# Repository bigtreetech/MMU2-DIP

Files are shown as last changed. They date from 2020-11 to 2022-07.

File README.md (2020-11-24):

# MMU2-DIP
Ported from [pruas3D](https://github.com/prusa3d/MM-control-01)  
Mcu: stm32f0c8  
Supports all types of drivers for bigtreetech,  
Supports TMC stall protection (tmc2209,tmc2130),  
Supports manual loading of filaments,  

# Modify configuration  
In firmware/MMU2/src/config.h  
Set the drive type, motor current, etc.

# Building  
It is recommended to use vscode to install the PlatformIO plugin for compilation.  

# Upgrade firmware in Windows  
1. Install firmware/Tool/cd340driver/CH341SER.EXE.  
2. Connect the usb  
3. Open firmware/Tool/flymcu/FlyMcu.exe.  
  ①. refreshing the port.  
  ②. select the corresponding port.  
  ③. setting the baud rate.  
  ④. Select the firmware.hex file.  
  ⑤. Set download parameters.  
  ⑥. click to start downloading.  
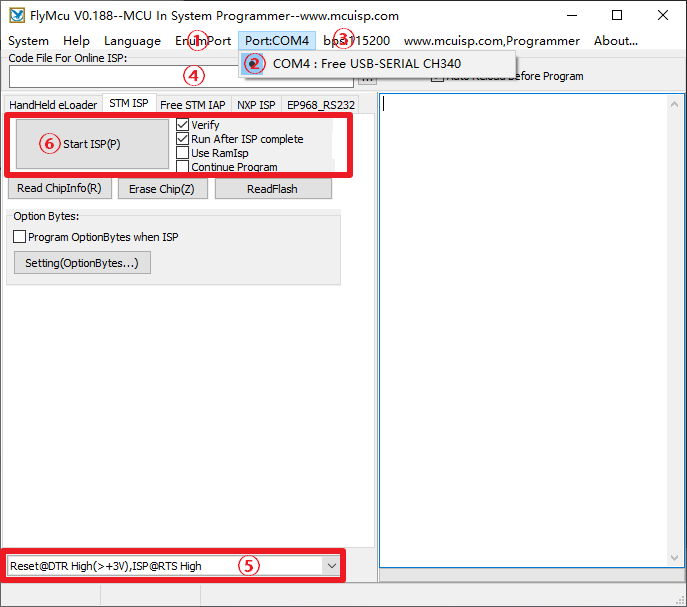
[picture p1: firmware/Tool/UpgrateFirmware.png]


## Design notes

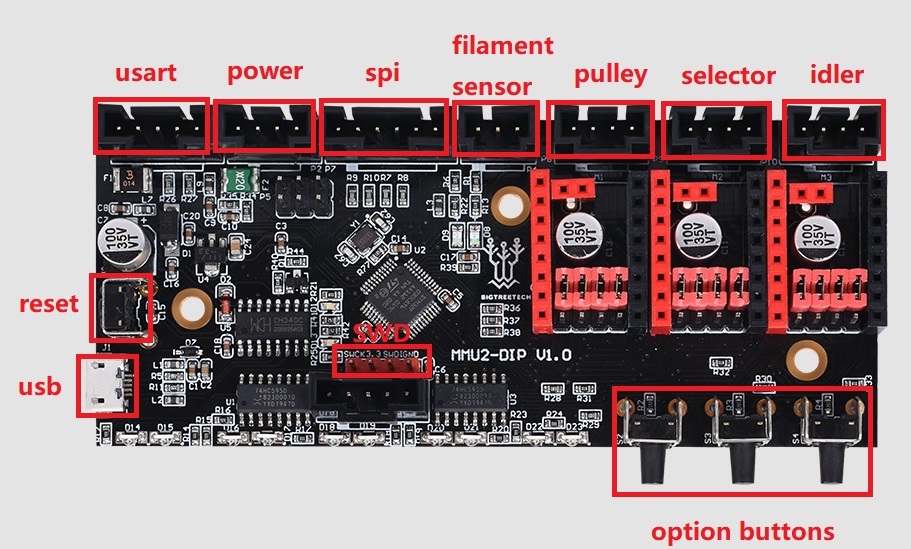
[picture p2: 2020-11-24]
firmware/Tool/ＭＭＵ2-DIP.jpg

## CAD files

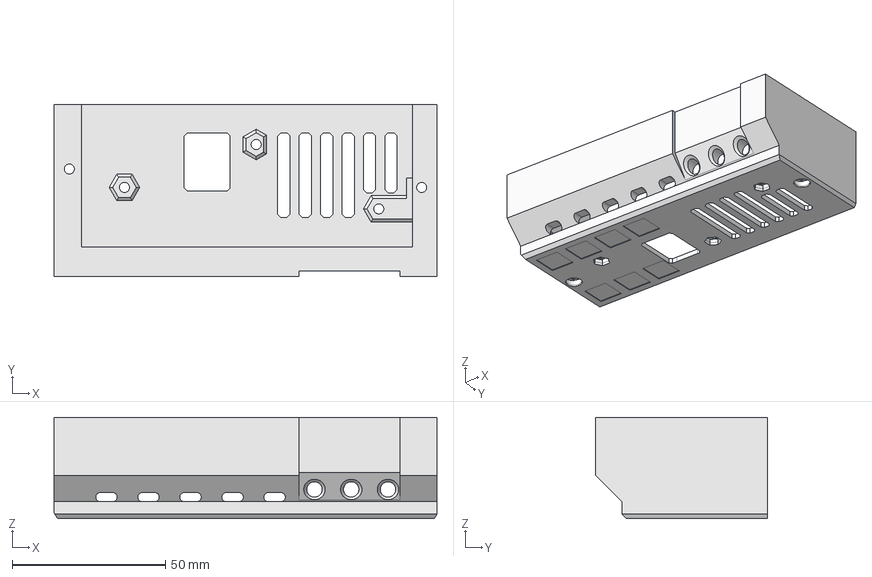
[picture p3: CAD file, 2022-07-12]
3DModel/STEP/mmu2-dip-ele-cover-v2.step
125.0 x 56.0 x 33.0 mm
prism016
prism017
text
Line001
Line
Line002
Line006
Line003
Line004
Line005
Line007
Line010
Line008
Line009
Line011
Line012
Line013
Line014
Line016
Line018
Line021
Line015
Line017
Line019
Line020
Line022
Line025
Line023
Line024
Line026
Line027
Line028
Line029
Line036
Line030
Line031
Line032
Line033
Line034
Line035
Line037
Line040
Line038
Line039
Line041
prism001
prism
prism002
prism003
prism004
frustum
frustum001
prism006
frustum002
prism007
RefineLinearExtrude
LinearExtrude
prism005
prism012
prism013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

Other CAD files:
3DModel/mmu2-dip-ele-cover-v2.stl

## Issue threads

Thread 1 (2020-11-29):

can't compile

gabwhoop, 2020-11-29:
any manual to how to compile mmu2 firmware???? this manual is not complete, im using vscode to compile my printers firmware without any issues but with mmu2 the check mark to compile doen't apear....big thanx im sorry for my english

bigtreetech, 2020-12-01:
Hi, we have tested the firmware to compile. You may need to wait for vscode to download the library.

gabwhoop, 2020-12-01:
ok big thanx my problem was i try to open the file using vscode instead platformIO thanx for your time

Closed 2020-12-02.

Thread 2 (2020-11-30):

pinout  and diagram

kakou-fr, 2020-11-30:
Hi,

Could you provide the pinout and shematics of this board in order to port the klipper firmware  on it.

bigtreetech, 2020-12-01:
OK, we have joined the plan

kakou-fr, 2020-12-01:
hi, i dont see any schematic in the current maaster

kakou-fr, 2020-12-09:
?

tobyworks, 2020-12-24:
Please provide a good pinout for this board like the skr 1.3 pinout diagram. We need to know the pin numbers for the steppers

tobyworks, 2021-01-02:
?

pstit006, 2021-01-05:
Has anyone got this board to work?

ellensp, 2022-03-31:
Circuit diagram have just been uploaded https://github.com/bigtreetech/MMU2-DIP/blob/master/hardware/MMU2-DIP.PDF

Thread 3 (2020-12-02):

MMU2-DIP no connect on mk3s

austaquio32, 2020-12-02:
Good afternoon, I'm trying to get your board to connect with a mk3s and it's impossible, I let the mk3s fully charge and restart the mmu2s-dip board and it still doesn't connect, do you have to change any position wire? Thank you very much.

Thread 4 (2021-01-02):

Can not connect skr 1.4 turbo

pstit006, 2021-01-02:
I have tried and tried I cannot get the mmu2 dip to communicate with the skr 1.4 turbo

pstit006, 2021-01-05:
Can anybody help

XylenC4, 2021-01-06:
I've got it working.
[Configuration_adv.txt](https://github.com/bigtreetech/MMU2-DIP/files/5777667/Configuration_adv.txt)
[Configuration.txt](https://github.com/bigtreetech/MMU2-DIP/files/5777668/Configuration.txt)

I'm using the TFT Socket so SERIAL0. To use this port it has to be disabled for general G-Command usage
//#define SERIAL_PORT_2 0

last but not least you have to define the Port (Serial is SERIAL0)
 // #define MMU2_SERIAL_PORT 0
  #define MMU2_SERIAL Serial

Make sure you're serial connection is connected right!
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

pstit006, 2021-01-06:
Ok I will give that a try I'm running a tft70 and I watched a video for using the i2c serial as serial 3 so I could keep my tft

XylenC4, 2021-01-06:
If you only use MARLIN Mode on the TFT (as I do) it will work without Serial0

pstit006, 2021-01-16:
Ok I've been trying to get this board to work I'm using the btt mmu2-dip board with tmc2209 drivers I've tried connecting to the tft port and still not talking to the mmu2-dip

AJAX2500, 2021-02-06:
Hey guys. I spent a lot of time smashing my head against a wall on trying to get the MMU board to connect to any board running 2.0.7.2 and ultimately I found that in the version.h of the MMU firmware file there is the following line.

static const uint16_t fw_buildnr = 130; //!< number of commits preceeding current HEAD

Once I changed this to the following everything connected up and worked perfect.

static const uint16_t fw_buildnr = 132; //!< number of commits preceeding current HEAD

Hope this is helpful to you!

Ven827, 2023-09-12:
Hey, just having a similar issue, my serial port seems to be 3.3V while the MMU2 needs 5V, I plugged it into a different 5V source and it works but I wasn't able to get any communication to happen. I'm also not able to compile if I comment out #define MMU2_SERIAL_PORT 0. Any help would be appreciated.

XylenC4, 2023-09-12:
I'll haven't compiled Marlin for a while as I'll moved over to a SKR PICO and KLIPPER and a Palette 2+ so take my answer with a grain of salt...

You shouldn't comment it out but replace the #define MMU2_SERIAL_PORT 0 with #define MMU2_SERIAL Serial. The MMU will require a serial port for communication, so there is no sense on disabling the port by removing the line.

Use a USB -> Serial Port adapter to verify the TTL (5V) serial communication to the MMU and the communication to your main board (which one do you use).

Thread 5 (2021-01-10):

Calibrate bowden length not working?

eightheads, 2021-01-10:
I cannot seem to calibrate the bowden length in the service menu of the MMU2. I can get to the menu, and to the calibrate section(selection #4), but when trying to start the calibration process it just blinks a single red LED on the #1 filament spot.

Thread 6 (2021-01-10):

MMU2 doesn't connect with GTR 1.0

av71966, 2021-01-10:
Hi. I tried to connect MMU2 to GTR 1.0 Board.  I connect it to UART3 (TFT connection)
MMU can reset from LCD menu, but don't load\uload filament and don't homing.
Marlin 2.0.7.4

Configuration
#define SERIAL_PORT -1
#define SERIAL_PORT_2 3

Configuration_adv
  #define MMU2_SERIAL_PORT 3
  #define MMU2_SERIAL Serial3

What's wrong?

XylenC4, 2021-01-14:
check out this thread (even if you use another board / chipset)

https://github.com/bigtreetech/MMU2-DIP/issues/4

-> Disable #define SERIAL_PORT_2 3 and #define MMU2_SERIAL_PORT 3

av71966, 2021-01-14:
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

Hi, i use UART 3 for TFT now. I tried to use serial Port 2 (ruspberry port) and have the same result...
If i want to use serial port 2 i need only define MMU2_SERIAL_PORT 2 and comment MMU2_SERIAL in Configuration ADV?

XylenC4, 2021-01-14:
You will need a separate serial connection to get this working.

//#define SERIAL_PORT_2 3
//#define MMU2_SERIAL_PORT 3
#define MMU2_SERIAL Serial2

I'm using the TFT but only in MARLIN MODE so no Serial Connection is needed for my TFT!

I recommend plugging in a Serial to USB connection to check if the connection is working. On Reset you will see an X0 sended by MARLIN.

av71966, 2021-01-21:
I fix problem.
Update marlin to new bugfix. Now it work perfect on uart6
https://github.com/MarlinFirmware/Marlin/pull/20771

pstit006, 2021-01-21:
How did you get the mmu2-dip to work can you provide a configuration and can you share a picture of how you have it hooked up I still can't seem to get this board working

Montezuma-69, 2021-05-18:
Av71966 Same problem here.
#define MMU2_SERIAL Serial3
works with TFT port

but

#define MMU2_SERIAL Serial6
does not work on USART6 at the WIFI port.

What did you set in configuration_adv.h?
Thank you so much

Closed 2021-01-21.

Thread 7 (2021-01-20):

Flash firmware without a Windows PC

iShavgula, 2021-01-20:
Hello,

Is there a way to flash the firmware using an Unix system, maybe via a ST-Link ?
What would the address be ?

Would be nice if there already was some documentation about this part.

Thanks

timurey, 2021-02-12:
Hello,
Use next command to flash firmware with st-link v.2 in `.pio/build/MMU2_F030C8` directory:
`openocd -f interface/stlink-v2.cfg -f target/stm32f0x.cfg -c "init; reset halt; stm32f0x unlock 0; reset halt; flash write_image erase firmware.hex; reset; exit"`

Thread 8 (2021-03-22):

Baudrate

Nickjallday, 2021-03-22:
So I can only get the mmu2-dip to connect to the SKR 1.4 via the i2c ports. Which it works.

I have two questions

1. how can I set the serial interface to 250000 bps instead of 115200. I would like my printer to be on 250000 bps. But when I adjust the uart1 in the config.h I can only get it to communicate with the SKR at 115200 bps.

side note: flymcu only allows communication at 115200 and 256000.

2. At 115200 I can get the mmu2 to communicate and print but it randomly drops communication and reboots the SKR. The terminal is flooded with “prevented cold extrusion” right before it reboots.

side note: I’m running a raspberry pi on the tft serial port.

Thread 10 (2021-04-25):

firmware.hex

nonaak, 2021-04-25:
where can i find firmware.hex?
or do i have to make it my self in platformIO?

Marlin display say "update mmu firmware" or do i somthing wrong? i folow the youtube of Chris Riley

thanks

ellensp, 2022-03-26:
Marlin has function
```CPP
/*
* Check if MMU has compatible firmware
 */
void MMU2::check_version() {
  if (buildnr < MMU_REQUIRED_FW_BUILDNR) {
    SERIAL_ERROR_MSG("Invalid MMU2 firmware. Version >= " STRINGIFY(MMU_REQUIRED_FW_BUILDNR) " required.");
    kill(GET_TEXT_F(MSG_KILL_MMU2_FIRMWARE));
  }
}

so it the firmware value  read form the mmu2 is less than MMU_REQUIRED_FW_BUILDNR
It will tell you to update the firmware

In Marlin MMU_REQUIRED_FW_BUILDNR is set with

`#define MMU_REQUIRED_FW_BUILDNR TERN(MMU2_MODE_12V, 132, 126)
`
Which says set MMU_REQUIRED_FW_BUILDNR to 132 if MMU2_MODE_12V is set
Otherwise set it to 126

This is set in MMU@-DIP source MMU2/src/version.h
`static const uint16_t fw_buildnr = 133; //!< number of commits preceeding current HEAD
`

ellensp, 2022-03-26:
You build the firmware from source.
This is required to set the type of stepper driver and stepper driver current

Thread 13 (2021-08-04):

Unable to upload firmware to board. Please help me.

newbie-0707, 2021-08-04:
MMU2-dip board is not port-aware.
Created "firmware.hex" file with Visual Studio Code program
You have currently installed the CH340 driver on Windows 10.
And when I buy the board, I connect it with my computer with the cable, so the device manager recognizes the port well.

Afterwards, the CH340 port is not detected even if you download and run the flyMCU program and press the EnumPort button

I tried to download STM32flash in another way and upload firmware with the command from the CMD window, but I get a "failed to init device." error message.

Install Ubuntu with Windows 10 Hyper-v to install the CH340 driver and try to install STM32flash without USB recognition.

Is the board broken? Or is it the wrong way I install it? I'd appreciate it if you could let me know.

It may sound strange because it's translated into a translator, but please.

newbie-0707, 2021-08-31:
Firmware upload was fixed
It does not work with stm32flash or Flymcu programs, so you can purchase ST-link, connect it to SWD, and upload it.

fjpg1970, 2023-04-20:
> Firmware upload was fixed It does not work with stm32flash or Flymcu programs, so you can purchase ST-link, connect it to SWD, and upload it.
>
> If it is not possible to connect via ST-link, connect 3.3v power to BOOT0 pin and reset it (this is not certain information) BOOT0 is connected to GND through the C17 capacitor on the board.

I don't have st-link, will putting 3.3v in boot0 work?

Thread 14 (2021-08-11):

unable to compile in PlatformIO

i8it, 2021-08-11:
I get several digital pin warnings and then I get a compile failure.  Is my board definition correct?

Here is the terminal window result:

> Executing task: C:\Users\Megamind\.platformio\penv\Scripts\platformio.exe run --environment MMU2_F030C8 <

Processing MMU2_F030C8 (platform: ststm32; board: MMU2_F030C8; framework: arduino)
----------------------------------------------------------------------------------------------------------------------------------------------------------------------Verbose mode can be enabled via `-v, --verbose` option
CONFIGURATION: https://docs.platformio.org/page/boards/ststm32/MMU2_F030C8.html
PLATFORM: ST STM32 (14.1.0) > MMU2_F030C8
HARDWARE: STM32F030C8T6 48MHz, 8KB RAM, 64KB Flash
DEBUG: Current (jlink) On-board (stlink) External (blackmagic, jlink)
PACKAGES:
 - framework-arduinoststm32 4.10700.200103 (1.7.0)
 - framework-cmsis 2.50700.210515 (5.7.0)
 - toolchain-gccarmnoneeabi 1.90201.191206 (9.2.1)
Warning! Cannot find linker script for the current target!

LDF: Library Dependency Finder -> http://bit.ly/configure-pio-ldf
LDF Modes: Finder ~ chain, Compatibility ~ soft
Library Manager: Installing TMCStepper @ >=0.6.2,<1.0.0
Library Manager: TMCStepper @ 0.7.1 has been installed!
Found 8 compatible libraries
Scanning dependencies...
Dependency Graph
|-- <TMCStepper> 0.7.1
|   |-- <SPI> 1.0
|-- <IWatchdog> 1.0.0
Building in release mode
Compiling .pio\build\MMU2_F030C8\FrameworkArduino\HardwareSerial.cpp.o
Compiling .pio\build\MMU2_F030C8\FrameworkArduino\HardwareTimer.cpp.o
Compiling .pio\build\MMU2_F030C8\FrameworkArduino\IPAddress.cpp.o
Compiling .pio\build\MMU2_F030C8\FrameworkArduino\Print.cpp.o
Compiling .pio\build\MMU2_F030C8\FrameworkArduino\RingBuffer.cpp.o
Compiling .pio\build\MMU2_F030C8\FrameworkArduino\Stream.cpp.o
Compiling .pio\build\MMU2_F030C8\FrameworkArduino\Tone.cpp.o
Compiling .pio\build\MMU2_F030C8\FrameworkArduino\USBSerial.cpp.o
Compiling .pio\build\MMU2_F030C8\FrameworkArduino\WInterrupts.cpp.o
Compiling .pio\build\MMU2_F030C8\FrameworkArduino\WMath.cpp.o
Compiling .pio\build\MMU2_F030C8\FrameworkArduino\WSerial.cpp.o
Compiling .pio\build\MMU2_F030C8\FrameworkArduino\WString.cpp.o
Compiling .pio\build\MMU2_F030C8\FrameworkArduino\abi.cpp.o
Compiling .pio\build\MMU2_F030C8\FrameworkArduino\avr\dtostrf.c.o
Compiling .pio\build\MMU2_F030C8\FrameworkArduino\board.c.o
Compiling .pio\build\MMU2_F030C8\FrameworkArduino\hooks.c.o
Compiling .pio\build\MMU2_F030C8\FrameworkArduino\itoa.c.o
Compiling .pio\build\MMU2_F030C8\FrameworkArduino\main.cpp.o
Compiling .pio\build\MMU2_F030C8\FrameworkArduino\new.cpp.o
Compiling .pio\build\MMU2_F030C8\FrameworkArduino\pins_arduino.c.o
Compiling .pio\build\MMU2_F030C8\FrameworkArduino\stm32\HAL\stm32yyxx_hal.c.o
Compiling .pio\build\MMU2_F030C8\FrameworkArduino\stm32\HAL\stm32yyxx_hal_adc.c.o
Compiling .pio\build\MMU2_F030C8\FrameworkArduino\stm32\HAL\stm32yyxx_hal_adc_ex.c.o
Compiling .pio\build\MMU2_F030C8\FrameworkArduino\stm32\HAL\stm32yyxx_hal_can.c.o
Compiling .pio\build\MMU2_F030C8\FrameworkArduino\stm32\HAL\stm32yyxx_hal_cec.c.o
Compiling .pio\build\MMU2_F030C8\FrameworkArduino\stm32\HAL\stm32yyxx_hal_comp.c.o
Compiling .pio\build\MMU2_F030C8\FrameworkArduino\stm32\HAL\stm32yyxx_hal_comp_ex.c.o
Compiling .pio\build\MMU2_F030C8\FrameworkArduino\stm32\HAL\stm32yyxx_hal_cordic.c.o
Compiling .pio\build\MMU2_F030C8\FrameworkArduino\stm32\HAL\stm32yyxx_hal_cortex.c.o
Compiling .pio\build\MMU2_F030C8\FrameworkArduino\stm32\HAL\stm32yyxx_hal_crc.c.o
Compiling .pio\build\MMU2_F030C8\FrameworkArduino\stm32\HAL\stm32yyxx_hal_crc_ex.c.o
Compiling .pio\build\MMU2_F030C8\FrameworkArduino\stm32\HAL\stm32yyxx_hal_cryp.c.o
Compiling .pio\build\MMU2_F030C8\FrameworkArduino\stm32\HAL\stm32yyxx_hal_cryp_ex.c.o
Compiling .pio\build\MMU2_F030C8\FrameworkArduino\stm32\HAL\stm32yyxx_hal_dac.c.o
Compiling .pio\build\MMU2_F030C8\FrameworkArduino\stm32\HAL\stm32yyxx_hal_dac_ex.c.o
Compiling .pio\build\MMU2_F030C8\FrameworkArduino\stm32\HAL\stm32yyxx_hal_dcmi.c.o
Compiling .pio\build\MMU2_F030C8\FrameworkArduino\stm32\HAL\stm32yyxx_hal_dcmi_ex.c.o
Compiling .pio\build\MMU2_F030C8\FrameworkArduino\stm32\HAL\stm32yyxx_hal_dfsdm.c.o
Compiling .pio\build\MMU2_F030C8\FrameworkArduino\stm32\HAL\stm32yyxx_hal_dfsdm_ex.c.o
Compiling .pio\build\MMU2_F030C8\FrameworkArduino\stm32\HAL\stm32yyxx_hal_dma.c.o
Compiling .pio\build\MMU2_F030C8\FrameworkArduino\stm32\HAL\stm32yyxx_hal_dma2d.c.o
Compiling .pio\build\MMU2_F030C8\FrameworkArduino\stm32\HAL\stm32yyxx_hal_dma_ex.c.o
Compiling .pio\build\MMU2_F030C8\FrameworkArduino\stm32\HAL\stm32yyxx_hal_dsi.c.o
Compiling .pio\build\MMU2_F030C8\FrameworkArduino\stm32\HAL\stm32yyxx_hal_eth.c.o
Compiling .pio\build\MMU2_F030C8\FrameworkArduino\stm32\HAL\stm32yyxx_hal_eth_ex.c.o
Compiling .pio\build\MMU2_F030C8\FrameworkArduino\stm32\HAL\stm32yyxx_hal_exti.c.o
Compiling .pio\build\MMU2_F030C8\FrameworkArduino\stm32\HAL\stm32yyxx_hal_fdcan.c.o
Compiling .pio\build\MMU2_F030C8\FrameworkArduino\stm32\HAL\stm32yyxx_hal_firewall.c.o
Compiling .pio\build\MMU2_F030C8\FrameworkArduino\stm32\HAL\stm32yyxx_hal_flash.c.o
Compiling .pio\build\MMU2_F030C8\FrameworkArduino\stm32\HAL\stm32yyxx_hal_flash_ex.c.o
Compiling .pio\build\MMU2_F030C8\FrameworkArduino\stm32\HAL\stm32yyxx_hal_flash_ramfunc.c.o
Compiling .pio\build\MMU2_F030C8\FrameworkArduino\stm32\HAL\stm32yyxx_hal_fmac.c.o
Compiling .pio\build\MMU2_F030C8\FrameworkArduino\stm32\HAL\stm32yyxx_hal_fmpi2c.c.o
Compiling .pio\build\MMU2_F030C8\FrameworkArduino\stm32\HAL\stm32yyxx_hal_fmpi2c_ex.c.o
Compiling .pio\build\MMU2_F030C8\FrameworkArduino\stm32\HAL\stm32yyxx_hal_gfxmmu.c.o
Compiling .pio\build\MMU2_F030C8\FrameworkArduino\stm32\HAL\stm32yyxx_hal_gpio.c.o
Compiling .pio\build\MMU2_F030C8\FrameworkArduino\stm32\HAL\stm32yyxx_hal_gpio_ex.c.o
Compiling .pio\build\MMU2_F030C8\FrameworkArduino\stm32\HAL\stm32yyxx_hal_hash.c.o
Compiling .pio\build\MMU2_F030C8\FrameworkArduino\stm32\HAL\stm32yyxx_hal_hash_ex.c.o
Compiling .pio\build\MMU2_F030C8\FrameworkArduino\stm32\HAL\stm32yyxx_hal_hcd.c.o
Compiling .pio\build\MMU2_F030C8\FrameworkArduino\stm32\HAL\stm32yyxx_hal_hrtim.c.o
Compiling .pio\build\MMU2_F030C8\FrameworkArduino\stm32\HAL\stm32yyxx_hal_hsem.c.o
Compiling .pio\build\MMU2_F030C8\FrameworkArduino\stm32\HAL\stm32yyxx_hal_i2c.c.o
Compiling .pio\build\MMU2_F030C8\FrameworkArduino\stm32\HAL\stm32yyxx_hal_i2c_ex.c.o
Compiling .pio\build\MMU2_F030C8\FrameworkArduino\stm32\HAL\stm32yyxx_hal_i2s.c.o
Compiling .pio\build\MMU2_F030C8\FrameworkArduino\stm32\HAL\stm32yyxx_hal_i2s_ex.c.o
Compiling .pio\build\MMU2_F030C8\FrameworkArduino\stm32\HAL\stm32yyxx_hal_ipcc.c.o
Compiling .pio\build\MMU2_F030C8\FrameworkArduino\stm32\HAL\stm32yyxx_hal_irda.c.o
Compiling .pio\build\MMU2_F030C8\FrameworkArduino\stm32\HAL\stm32yyxx_hal_iwdg.c.o
Compiling .pio\build\MMU2_F030C8\FrameworkArduino\stm32\HAL\stm32yyxx_hal_jpeg.c.o
Compiling .pio\build\MMU2_F030C8\FrameworkArduino\stm32\HAL\stm32yyxx_hal_lcd.c.o
Compiling .pio\build\MMU2_F030C8\FrameworkArduino\stm32\HAL\stm32yyxx_hal_lptim.c.o
Compiling .pio\build\MMU2_F030C8\FrameworkArduino\stm32\HAL\stm32yyxx_hal_ltdc.c.o
Compiling .pio\build\MMU2_F030C8\FrameworkArduino\stm32\HAL\stm32yyxx_hal_ltdc_ex.c.o
Compiling .pio\build\MMU2_F030C8\FrameworkArduino\stm32\HAL\stm32yyxx_hal_mdios.c.o
Compiling .pio\build\MMU2_F030C8\FrameworkArduino\stm32\HAL\stm32yyxx_hal_mdma.c.o
Compiling .pio\build\MMU2_F030C8\FrameworkArduino\stm32\HAL\stm32yyxx_hal_mmc.c.o
Compiling .pio\build\MMU2_F030C8\FrameworkArduino\stm32\HAL\stm32yyxx_hal_mmc_ex.c.o
Compiling .pio\build\MMU2_F030C8\FrameworkArduino\stm32\HAL\stm32yyxx_hal_msp_template.c.o
Compiling .pio\build\MMU2_F030C8\FrameworkArduino\stm32\HAL\stm32yyxx_hal_nand.c.o
Compiling .pio\build\MMU2_F030C8\FrameworkArduino\stm32\HAL\stm32yyxx_hal_nor.c.o
Compiling .pio\build\MMU2_F030C8\FrameworkArduino\stm32\HAL\stm32yyxx_hal_opamp.c.o
Compiling .pio\build\MMU2_F030C8\FrameworkArduino\stm32\HAL\stm32yyxx_hal_opamp_ex.c.o
Compiling .pio\build\MMU2_F030C8\FrameworkArduino\stm32\HAL\stm32yyxx_hal_ospi.c.o
Compiling .pio\build\MMU2_F030C8\FrameworkArduino\stm32\HAL\stm32yyxx_hal_pccard.c.o
Compiling .pio\build\MMU2_F030C8\FrameworkArduino\stm32\HAL\stm32yyxx_hal_pcd.c.o
Compiling .pio\build\MMU2_F030C8\FrameworkArduino\stm32\HAL\stm32yyxx_hal_pcd_ex.c.o
Compiling .pio\build\MMU2_F030C8\FrameworkArduino\stm32\HAL\stm32yyxx_hal_pka.c.o
Compiling .pio\build\MMU2_F030C8\FrameworkArduino\stm32\HAL\stm32yyxx_hal_pwr.c.o
Compiling .pio\build\MMU2_F030C8\FrameworkArduino\stm32\HAL\stm32yyxx_hal_pwr_ex.c.o
Compiling .pio\build\MMU2_F030C8\FrameworkArduino\stm32\HAL\stm32yyxx_hal_qspi.c.o
Compiling .pio\build\MMU2_F030C8\FrameworkArduino\stm32\HAL\stm32yyxx_hal_ramecc.c.o
Compiling .pio\build\MMU2_F030C8\FrameworkArduino\stm32\HAL\stm32yyxx_hal_rcc.c.o
Compiling .pio\build\MMU2_F030C8\FrameworkArduino\stm32\HAL\stm32yyxx_hal_rcc_ex.c.o
Compiling .pio\build\MMU2_F030C8\FrameworkArduino\stm32\HAL\stm32yyxx_hal_rng.c.o
Compiling .pio\build\MMU2_F030C8\FrameworkArduino\stm32\HAL\stm32yyxx_hal_rtc.c.o
Compiling .pio\build\MMU2_F030C8\FrameworkArduino\stm32\HAL\stm32yyxx_hal_rtc_ex.c.o
Compiling .pio\build\MMU2_F030C8\FrameworkArduino\stm32\HAL\stm32yyxx_hal_sai.c.o
Compiling .pio\build\MMU2_F030C8\FrameworkArduino\stm32\HAL\stm32yyxx_hal_sai_ex.c.o
Compiling .pio\build\MMU2_F030C8\FrameworkArduino\stm32\HAL\stm32yyxx_hal_sd.c.o
Compiling .pio\build\MMU2_F030C8\FrameworkArduino\stm32\HAL\stm32yyxx_hal_sd_ex.c.o
Compiling .pio\build\MMU2_F030C8\FrameworkArduino\stm32\HAL\stm32yyxx_hal_sdadc.c.o
Compiling .pio\build\MMU2_F030C8\FrameworkArduino\stm32\HAL\stm32yyxx_hal_sdram.c.o
Compiling .pio\build\MMU2_F030C8\FrameworkArduino\stm32\HAL\stm32yyxx_hal_smartcard.c.o
Compiling .pio\build\MMU2_F030C8\FrameworkArduino\stm32\HAL\stm32yyxx_hal_smartcard_ex.c.o
Compiling .pio\build\MMU2_F030C8\FrameworkArduino\stm32\HAL\stm32yyxx_hal_smbus.c.o
Compiling .pio\build\MMU2_F030C8\FrameworkArduino\stm32\HAL\stm32yyxx_hal_spdifrx.c.o
Compiling .pio\build\MMU2_F030C8\FrameworkArduino\stm32\HAL\stm32yyxx_hal_spi.c.o
Compiling .pio\build\MMU2_F030C8\FrameworkArduino\stm32\HAL\stm32yyxx_hal_spi_ex.c.o
Compiling .pio\build\MMU2_F030C8\FrameworkArduino\stm32\HAL\stm32yyxx_hal_sram.c.o
Compiling .pio\build\MMU2_F030C8\FrameworkArduino\stm32\HAL\stm32yyxx_hal_swpmi.c.o
Compiling .pio\build\MMU2_F030C8\FrameworkArduino\stm32\HAL\stm32yyxx_hal_tim.c.o
Compiling .pio\build\MMU2_F030C8\FrameworkArduino\stm32\HAL\stm32yyxx_hal_tim_ex.c.o
Compiling .pio\build\MMU2_F030C8\FrameworkArduino\stm32\HAL\stm32yyxx_hal_timebase_rtc_alarm_template.c.o
Compiling .pio\build\MMU2_F030C8\FrameworkArduino\stm32\HAL\stm32yyxx_hal_timebase_rtc_wakeup_template.c.o
Compiling .pio\build\MMU2_F030C8\FrameworkArduino\stm32\HAL\stm32yyxx_hal_timebase_tim_template.c.o
Compiling .pio\build\MMU2_F030C8\FrameworkArduino\stm32\HAL\stm32yyxx_hal_tsc.c.o
Compiling .pio\build\MMU2_F030C8\FrameworkArduino\stm32\HAL\stm32yyxx_hal_uart.c.o
Compiling .pio\build\MMU2_F030C8\FrameworkArduino\stm32\HAL\stm32yyxx_hal_uart_ex.c.o
Compiling .pio\build\MMU2_F030C8\FrameworkArduino\stm32\HAL\stm32yyxx_hal_usart.c.o
Compiling .pio\build\MMU2_F030C8\FrameworkArduino\stm32\HAL\stm32yyxx_hal_usart_ex.c.o
Compiling .pio\build\MMU2_F030C8\FrameworkArduino\stm32\HAL\stm32yyxx_hal_wwdg.c.o
Compiling .pio\build\MMU2_F030C8\FrameworkArduino\stm32\LL\stm32yyxx_ll_adc.c.o
Compiling .pio\build\MMU2_F030C8\FrameworkArduino\stm32\LL\stm32yyxx_ll_bdma.c.o
Compiling .pio\build\MMU2_F030C8\FrameworkArduino\stm32\LL\stm32yyxx_ll_comp.c.o
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
pewe0001, 2022-02-22:
have you solved the problem?
i have the same and looking for al solving

ellensp, 2022-03-26:
I forced the platform version  to 12.1  vs the 14.1 your trying to use

Ie In platformio.ini

Find
```
[env:MMU2_F030C8]
platform  = ststm32
```

to
```
[env:MMU2_F030C8]
platform  = ststm32@~12.1
```

This compiles for me

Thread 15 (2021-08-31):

I want to reverse the filament detection sensor contact

newbie-0707, 2021-08-31:
As a filament detection sensor, the proximity sensor was purchased as an NPN NO type and the filament detection was reversed.
Is there any way to use this sensor now by modifying the firmware?
If so, I'd appreciate it if you could tell me where to fix it.

ellensp, 2022-03-26:
Read the Config.h
This a setting that is already there

#define FILAMENT_SENSOR_INVERTING   true // Set to true to invert the logic of the filament_Sensor.

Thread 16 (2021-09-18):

Impossible Compilation

FNeo31, 2021-09-18:
I get this error and I can't compile.

Tried another versions of PlatformIO and framework-arduinoststm32 and anything result.
Can anyone help?

```
Processing MMU2_F030C8 (platform: ststm32; board: MMU2_F030C8; framework: arduino)
----------------------------------------------------------------------------------------------------------------------------------------------------------------------------------------------------------------------------------------------Verbose mode can be enabled via `-v, --verbose` option
CONFIGURATION: https://docs.platformio.org/page/boards/ststm32/MMU2_F030C8.html
PLATFORM: ST STM32 (14.0.1) > MMU2_F030C8
HARDWARE: STM32F030C8T6 48MHz, 8KB RAM, 64KB Flash
DEBUG: Current (jlink) On-board (stlink) External (blackmagic, jlink)
PACKAGES:
 - framework-arduinoststm32 4.10700.200103 (1.7.0)
 - framework-cmsis 2.50700.210515 (5.7.0)
 - toolchain-gccarmnoneeabi 1.90201.191206 (9.2.1)
Error: Missing PlatformIO build script C:\Users\fjpin\.platformio\packages\framework-arduinoststm32@4.10700.200103\tools\platformio\platformio-build.py!
========================================================================================================= [FAILED] Took 0.80 seconds =========================================================================================================The terminal process "C:\Users\fjpin\.platformio\penv\Scripts\platformio.exe 'run'" terminated with exit code: 1.
```

newbie-0707, 2021-10-30:
me too...i want compile...

newbie-0707, 2021-11-05:
Once the compilation was successful.

I'll just share with you how I did it. I hope you give it a try

Install another version of framework-arduinoststm32

Change the number after "platform_packages = framework-arduinoststm32@>=4.10700,<4.10800" in the platformio.ini file.

For example 4.10800, < 4.10900

After that, if you look in the tools folder in the newly installed framework-arduinoststm32 folder, there is a .flake8 file After copying this

Paste it in C:\Users\calca\.platformio\packages\framework-arduinoststm32@4.10700.200103\tools

Create a new folder in the tools folder, change the folder name to platformio, and put the platformio-build.py file in the platformio folder.

Add library in VScode PlatformIO IDE PIO home.
softwareserial
TMC stepper

Add Platforms
ststm32
atmel AVR (not sure)

newbie-0707, 2021-11-05:
Look up the contents of the platformio.ini set file

; PlatformIO Project Configuration File
;
;   Build options: build flags, source filter
;   Upload options: custom upload port, speed and extra flags
;   Library options: dependencies, extra library storages
;   Advanced options: extra scripting
;
; Please visit documentation for the other options and examples
; https://docs.platformio.org/page/projectconf.html

[platformio]
src_dir = MMU2
boards_dir = buildroot/share/PlatformIO/boards
default_envs = MMU2_F030C8

[common]
default_src_filter = +<src/*>
extra_scripts = pre:buildroot/share/PlatformIO/scripts/common-cxxflags.py
lib_deps = TMCStepper@>=0.6.2,<1.0.0
build_flags = -fmax-errors=5

[env:MMU2_F030C8]
platform = ststm32
extends = common
board = MMU2_F030C8
framework = arduino
platform_packages = framework-arduinoststm32@>=4.10700,<4.10800
build_flags = ${common.build_flags}
	-IMMU2/src/HAL -std=gnu++14
src_filter = ${common.default_src_filter}
extra_scripts = ${common.extra_scripts}
	buildroot/share/PlatformIO/scripts/generic_create_variant.py
	buildroot/share/PlatformIO/scripts/MMU2_F030C8.py
lib_deps =
	${common.lib_deps}
	teemuatlut/TMCStepper@^0.7.3
	fysetc/SoftwareSerialM@^1.0.0
lib_ignore = SoftwareSerialM
upload_protocol = jlink
debug_tool = jlink

newbie-0707, 2021-11-05:
c_cpp_properties.json Set contents are also uploaded. I wish you refer to that

Please focus on includepath

//
// !!! WARNING !!! AUTO-GENERATED FILE!
// PLEASE DO NOT MODIFY IT AND USE "platformio.ini":
// https://docs.platformio.org/page/projectconf/section_env_build.html#build-flags
//
{
    "configurations": [
        {
            "name": "PlatformIO",
            "includePath": [
                //"C:/Users/calca/Downloads/MMU2-DIP-master/MMU2-DIP-master/firmware/include",
                "C:/Users/calca/Downloads/MMU2-DIP-master/MMU2-DIP-master/firmware/MMU2",
                "C:/Users/calca/.platformio/packages/framework-arduinoststm32@4.10700.200103/libraries/IWatchdog/src",
                "C:/Users/calca/Downloads/MMU2-DIP-master/MMU2-DIP-master/firmware/.pio/libdeps/MMU2_F030C8/U8glib-HAL/src",
                "C:/Users/calca/Downloads/MMU2-DIP-master/MMU2-DIP-master/firmware/.pio/libdeps/MMU2_F030C8/TMCStepper/src",
                "C:/Users/calca/.platformio/packages/framework-arduinoststm32@4.10700.200103/libraries/SPI/src",
                "C:/Users/calca/Downloads/MMU2-DIP-master/MMU2-DIP-master/firmware/.pio/libdeps/MMU2_F030C8/SoftwareSerialM",
                "C:/Users/calca/Downloads/MMU2-DIP-master/MMU2-DIP-master/firmware/MMU2/src/HAL",
                "C:/Users/calca/.platformio/packages/framework-arduinoststm32@4.10700.200103/cores/arduino/avr",
                "C:/Users/calca/.platformio/packages/framework-arduinoststm32@4.10700.200103/cores/arduino/stm32",
                "C:/Users/calca/.platformio/packages/framework-arduinoststm32@4.10700.200103/cores/arduino/stm32/LL",
                "C:/Users/calca/.platformio/packages/framework-arduinoststm32@4.10700.200103/cores/arduino/stm32/usb",
                //"C:/Users/calca/.platformio/packages/framework-arduinoststm32@4.10700.200103/cores/arduino/stm32/OpenAMP",
                "C:/Users/calca/.platformio/packages/framework-arduinoststm32@4.10700.200103/cores/arduino/stm32/usb/hid",
                "C:/Users/calca/.platformio/packages/framework-arduinoststm32@4.10700.200103/cores/arduino/stm32/usb/cdc",
                "C:/Users/calca/.platformio/packages/framework-arduinoststm32@4.10700.200103/system/Drivers/STM32F0xx_HAL_Driver/Inc",
                "C:/Users/calca/.platformio/packages/framework-arduinoststm32@4.10700.200103/system/Drivers/STM32F0xx_HAL_Driver/Src",
                "C:/Users/calca/.platformio/packages/framework-arduinoststm32@4.10700.200103/system/STM32F0xx",
                "C:/Users/calca/.platformio/packages/framework-arduinoststm32@4.10700.200103/system/Middlewares/ST/STM32_USB_Device_Library/Core/Inc",
                "C:/Users/calca/.platformio/packages/framework-arduinoststm32@4.10700.200103/system/Middlewares/ST/STM32_USB_Device_Library/Core/Src",
               // "C:/Users/calca/.platformio/packages/framework-arduinoststm32@4.10700.200103/system/Middlewares/OpenAMP",
                //"C:/Users/calca/.platformio/packages/framework-arduinoststm32@4.10700.200103/system/Middlewares/OpenAMP/open-amp/lib/include",
                //"C:/Users/calca/.platformio/packages/framework-arduinoststm32@4.10700.200103/system/Middlewares/OpenAMP/libmetal/lib/include",
                //"C:/Users/calca/.platformio/packages/framework-arduinoststm32@4.10700.200103/system/Middlewares/OpenAMP/virtual_driver",
                "C:/Users/calca/.platformio/packages/framework-cmsis/CMSIS/Core/Include",
                "C:/Users/calca/.platformio/packages/framework-arduinoststm32@4.10700.200103/system/Drivers/CMSIS/Device/ST/STM32F0xx/Include",
                "C:/Users/calca/.platformio/packages/framework-arduinoststm32@4.10700.200103/system/Drivers/CMSIS/Device/ST/STM32F0xx/Source/Templates/gcc",
                "C:/Users/calca/.platformio/packages/framework-cmsis/CMSIS/DSP/Include",
                "C:/Users/calca/.platformio/packages/framework-cmsis/CMSIS/DSP/PrivateInclude",
                "C:/Users/calca/.platformio/packages/framework-arduinoststm32@4.10700.200103/cores/arduino",
                "C:/Users/calca/.platformio/packages/framework-arduinoststm32@4.10700.200103/variants/MMU2_F030C8",
                "C:/Users/calca/.platformio/packages/framework-arduinoststm32@4.10700.200103/libraries/Wire/src",
                "C:/Users/calca/.platformio/packages/framework-arduinoststm32@4.10700.200103/libraries/EEPROM/src",
                "C:/Users/calca/.platformio/packages/framework-arduinoststm32@4.10700.200103/libraries/Keyboard/src",
                "C:/Users/calca/.platformio/packages/framework-arduinoststm32@4.10700.200103/libraries/Mouse/src",
                "C:/Users/calca/.platformio/packages/framework-arduinoststm32@4.10700.200103/libraries/Servo/src",
                ""
            ],
            "browse": {
                "limitSymbolsToIncludedHeaders": true,
                "path": [
                    //"C:/Users/calca/Downloads/MMU2-DIP-master/MMU2-DIP-master/firmware/include",
                    "C:/Users/calca/Downloads/MMU2-DIP-master/MMU2-DIP-master/firmware/MMU2",
                    "C:/Users/calca/.platformio/packages/framework-arduinoststm32@4.10700.200103/libraries/IWatchdog/src",
                    "C:/Users/calca/Downloads/MMU2-DIP-master/MMU2-DIP-master/firmware/.pio/libdeps/MMU2_F030C8/U8glib-HAL/src",
                    "C:/Users/calca/Downloads/MMU2-DIP-master/MMU2-DIP-master/firmware/.pio/libdeps/MMU2_F030C8/TMCStepper/src",
                    "C:/Users/calca/.platformio/packages/framework-arduinoststm32@4.10700.200103/libraries/SPI/src",
                    "C:/Users/calca/Downloads/MMU2-DIP-master/MMU2-DIP-master/firmware/.pio/libdeps/MMU2_F030C8/SoftwareSerialM",
                    "C:/Users/calca/Downloads/MMU2-DIP-master/MMU2-DIP-master/firmware/MMU2/src/HAL",
                    "C:/Users/calca/.platformio/packages/framework-arduinoststm32@4.10700.200103/cores/arduino/avr",
                    "C:/Users/calca/.platformio/packages/framework-arduinoststm32@4.10700.200103/cores/arduino/stm32",
                    "C:/Users/calca/.platformio/packages/framework-arduinoststm32@4.10700.200103/cores/arduino/stm32/LL",
                    "C:/Users/calca/.platformio/packages/framework-arduinoststm32@4.10700.200103/cores/arduino/stm32/usb",
                    //"C:/Users/calca/.platformio/packages/framework-arduinoststm32@4.10700.200103/cores/arduino/stm32/OpenAMP",
                    "C:/Users/calca/.platformio/packages/framework-arduinoststm32@4.10700.200103/cores/arduino/stm32/usb/hid",
                    "C:/Users/calca/.platformio/packages/framework-arduinoststm32@4.10700.200103/cores/arduino/stm32/usb/cdc",
                    "C:/Users/calca/.platformio/packages/framework-arduinoststm32@4.10700.200103/system/Drivers/STM32F0xx_HAL_Driver/Inc",
                    "C:/Users/calca/.platformio/packages/framework-arduinoststm32@4.10700.200103/system/Drivers/STM32F0xx_HAL_Driver/Src",
                    "C:/Users/calca/.platformio/packages/framework-arduinoststm32@4.10700.200103/system/STM32F0xx",
                    "C:/Users/calca/.platformio/packages/framework-arduinoststm32@4.10700.200103/system/Middlewares/ST/STM32_USB_Device_Library/Core/Inc",
                    "C:/Users/calca/.platformio/packages/framework-arduinoststm32@4.10700.200103/system/Middlewares/ST/STM32_USB_Device_Library/Core/Src",
                    //"C:/Users/calca/.platformio/packages/framework-arduinoststm32@4.10700.200103/system/Middlewares/OpenAMP",
                    //"C:/Users/calca/.platformio/packages/framework-arduinoststm32@4.10700.200103/system/Middlewares/OpenAMP/open-amp/lib/include",
                    //"C:/Users/calca/.platformio/packages/framework-arduinoststm32@4.10700.200103/system/Middlewares/OpenAMP/libmetal/lib/include",
                    //"C:/Users/calca/.platformio/packages/framework-arduinoststm32@4.10700.200103/system/Middlewares/OpenAMP/virtual_driver",
                    "C:/Users/calca/.platformio/packages/framework-cmsis/CMSIS/Core/Include",
                    "C:/Users/calca/.platformio/packages/framework-arduinoststm32@4.10700.200103/system/Drivers/CMSIS/Device/ST/STM32F0xx/Include",
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

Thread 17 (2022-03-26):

3d model 3DModel/Electronics%20cover%20MMU2.STL is not good

ellensp, 2022-03-26:
This is a very bad model. Almost nothing lines up.
Considering you make the PCB and have all the dimensions, this is really not acceptable.

With USB on the left and PCB up with component on top for orientation

The two screw mounts on the bottom are ok. Why isn't there a 3rd one ?

Hole for USB is not tall enough.You cannot insert provided USB cable into the port, and if you try you will rip the USB port off of the PCB.

Reset button hole does not line up with reset button, hole is two low.

Indicator LEDs do not align up with the holes for them, To far left and incorrect spacing. Left most hole is out by 3.5 mm!

Button holes are all off center. Two far right and incorrect spacing.

Please try again. Or provide CAD so we can fit it

thisiskeithb, 2023-07-30:
Fixed in https://github.com/bigtreetech/MMU2-DIP/pull/19

Closed 2024-09-28.

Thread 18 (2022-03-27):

MMU2-DIP will not reset on reset line

ellensp, 2022-03-27:
I have a brand new MMU2-DIP

I  connected to a FTDI interface to it since I was having issue getting it to communicate to do some diagnosis

FTDI -> P1 on MMU2-DIP
5v -> 5v
RX-TX
TX-RX
GND-GND

It powers on and says "start" @ 115200 baud as it should.

When I press the reset button on the side it resets as expected and the D8 LED lights up RED momentarily and It says start again over serial.

But when I connect the reset pin on P1 to GND momentarily, It does not restart, D8 LED does not light up and I don't get a start message,

The P1 reset line is required for the MMU2 to work. (with hardware reset mode)

Please advise.

I could diagnose this further, if you had uploaded a circuit diagram as requested,
Edit: Circuit diagrams has just been uploaded.

Update. If I use reset pin on ICSP header, it resets as expected,
If I measure voltage on reset pin on ICSP header I get 3.3v pull up as I would expect
But if I measure voltage on reset pin on P1, I get nothing.

ellensp, 2022-03-30:
Please Confirm that a hardware reset of the MMU2-DIP by momentarily holding reset pin on P1 low is meant to work.
Switching to software reset and sending X0 over serial to MMU2-DIP resets as expected.

geheimo66, 2022-04-08:
for the reset, you have to remove the capacitor c15 at the reset button. then the reset works via p1.

Closed 2022-04-08.

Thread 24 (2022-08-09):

Is it possible to increase the number of extruders on MMU-DIP?

LoloMake60, 2022-08-09:
Hi,

I wanted to know if it was possible to increase the number of extruders to 10?

This should be possible by modifying the code and the led codes.

Thanks.

LoloMake60, 2022-08-09:
LED indication of states
//!
//! RG | RG | RG | RG | RG | meaning
//! -- | -- | -- | -- | -- | ------------------------
//! 01 | 00 | 00 | 00 | 00 | filament 1
//! 00 | 01 | 00 | 00 | 00 | filament 2
//! 00 | 00 | 01 | 00 | 00 | filament 3
//! 00 | 00 | 00 | 01 | 00 | filament 4
//! 00 | 00 | 00 | 00 | 01 | filament 5
//! 01 | 01 | 00 | 00 | 00 | filament 6
//! 01 | 00 | 01 | 00 | 00 | filament 7
//! 01 | 00 | 00 | 01 | 00 | filament 8
//! 01 | 00 | 00 | 00 | 01 | filament 9
//! 01 | 01 | 01 | 01 | 01 | filament 10
//! 00 | 00 | 00 | 00 | bb | park position

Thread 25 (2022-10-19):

12v 24v no power

Drew3164, 2022-10-19:
I've hook up the power correctly.... But the board is not powering up. Works with USB no problem and uploaded HEX. file

I've tried it with 12v and 24v ....? not really a lot of info on this board ?

Any help thanks!!

Drew3164, 2022-10-19:
Fixed

Needs ground and 5v form other board.

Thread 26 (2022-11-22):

MMu2 doesn't recognize commands from SKR 1.4

ChGeorgi, 2022-11-22:
Hi, i have connected the MMU2 to my SKR 1.4.
I can not communicate with MMU2. Wiring is ok.
when i connect my PC to SKR i get the MMU2 commands and when i connect my PC to MMU2 i can control MMU2.
when i do a reset i can send the X0, S1, S2 command from my PC and have the TX of MMU2 connected to my SKR it works.
so it seems, that SKR commands  are not recognized by MMU.
do i need a level shifter or something else?
regards
Christian

ChGeorgi, 2022-11-23:
I fixed it.
iam using the sw reset.
during the start the first command was ?X0 instead of X0

pstit006, 2022-12-06:
Can you share your settings I'm having the same issue

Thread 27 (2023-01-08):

SKR 1.4 turbo +MMU2-DIP

myriccardo, 2023-01-08:
By connecting the two boards and using the Marlin 2.0.8 firmware downloaded precompiled from the Ender_5 configuration I have only one problem, when the MMU2 sensor does not see the filament while the working machine stops everything and restarts the program and Pronterface displays :(Can' t write to printer (disconnected ?):
Traceback (most recent call last):
   File "printrun\printcore.py", line 744, in _send
   File "serial\serialwin32.py", line 317, in write
serial.serialutil.SerialException: WriteFile failed (PermissionError(13, 'The device does not recognize the command.', None, 22))

How to fix this
Thank you

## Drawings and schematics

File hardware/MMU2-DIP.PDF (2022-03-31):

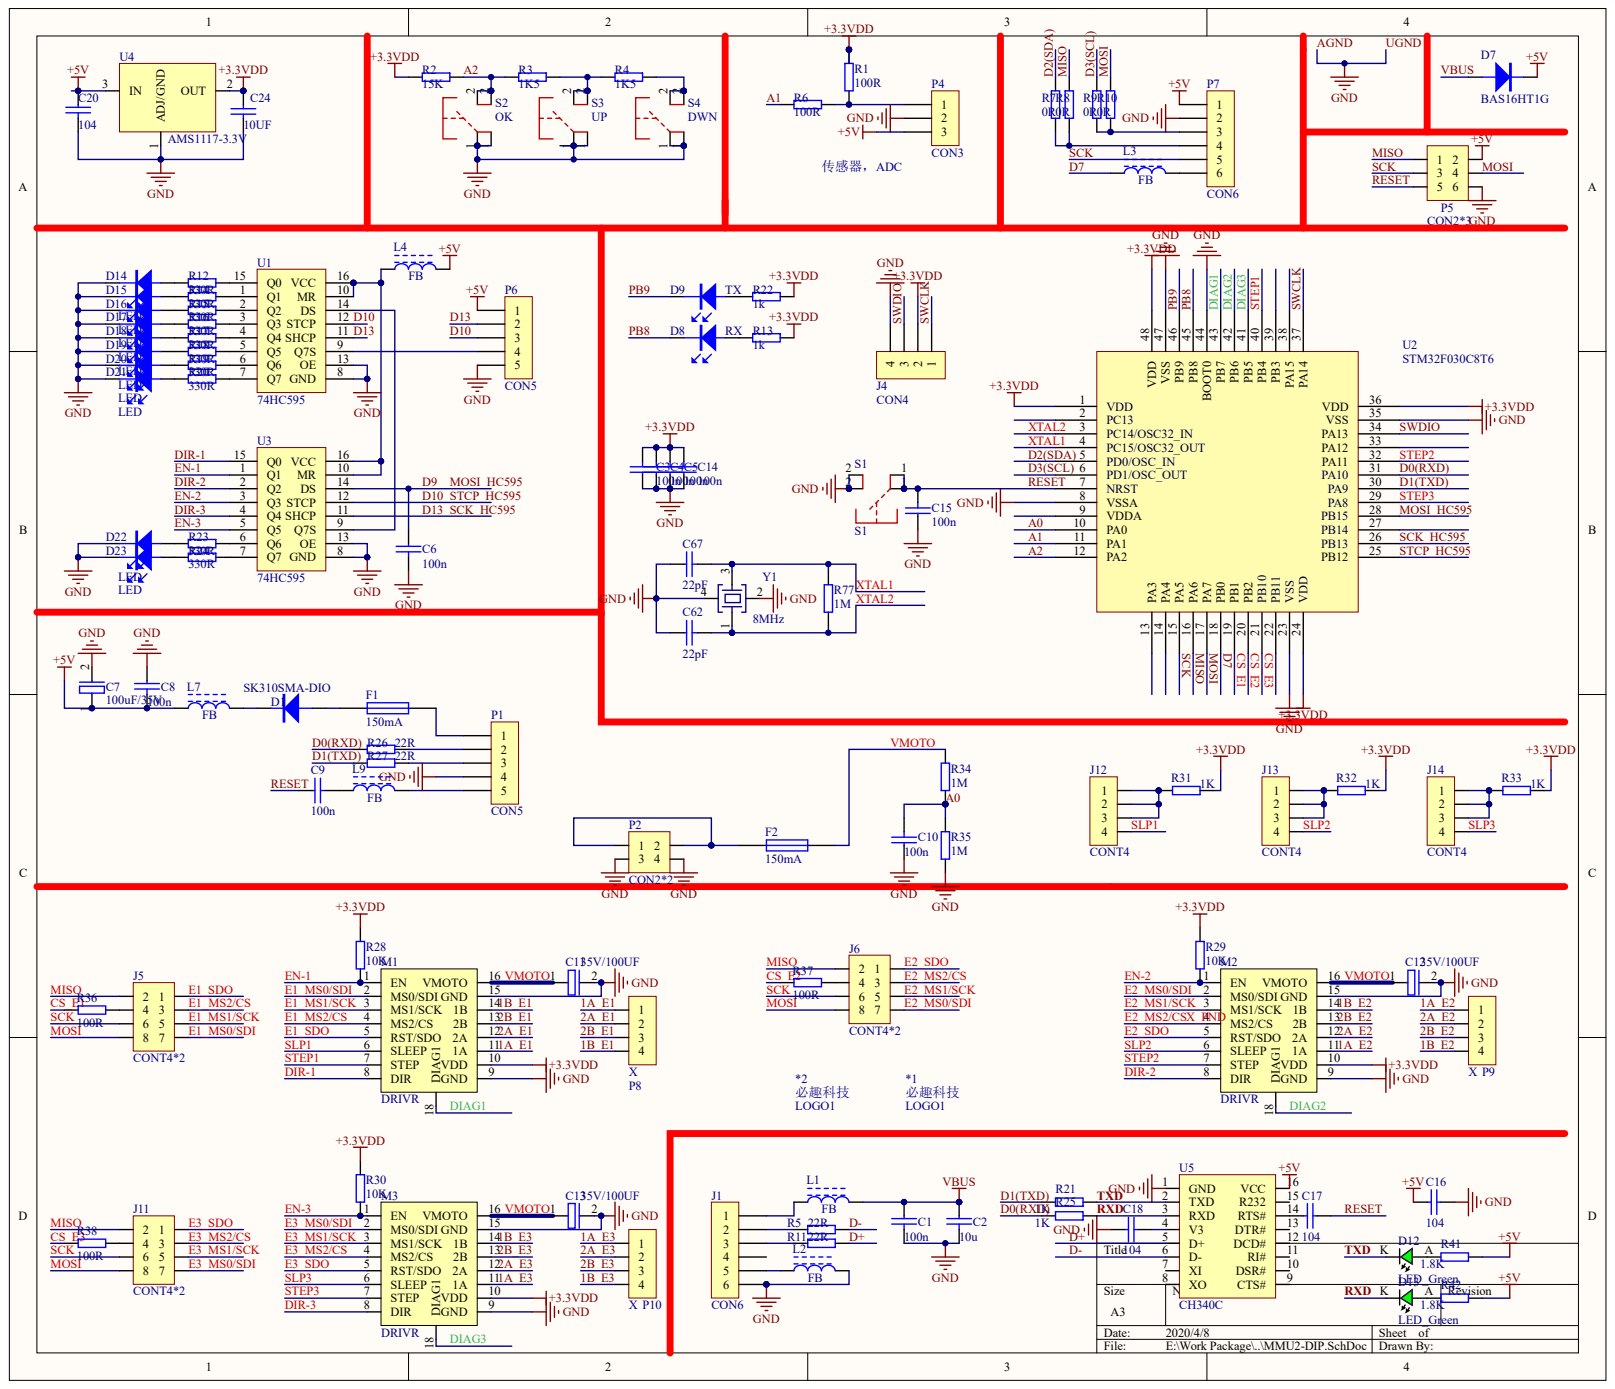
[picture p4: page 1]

1 | 2 | 3 +3.3VDD | 4

U4 | +3.3VDD | | | AGND UGND | D7 +5V

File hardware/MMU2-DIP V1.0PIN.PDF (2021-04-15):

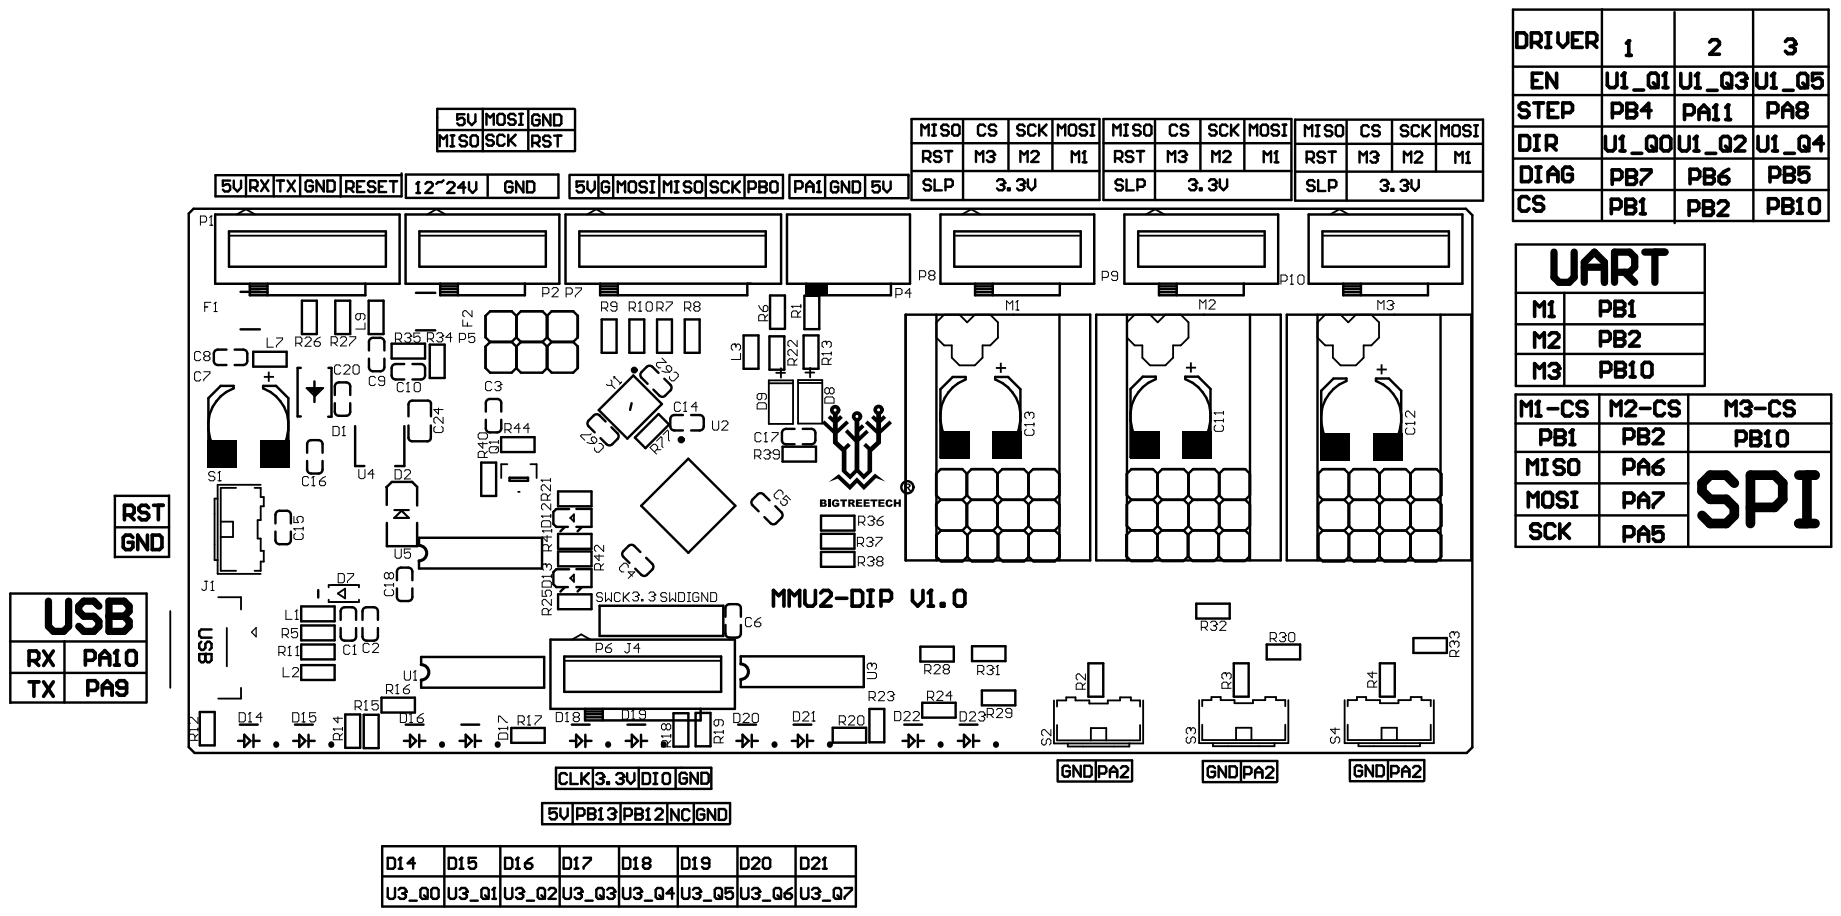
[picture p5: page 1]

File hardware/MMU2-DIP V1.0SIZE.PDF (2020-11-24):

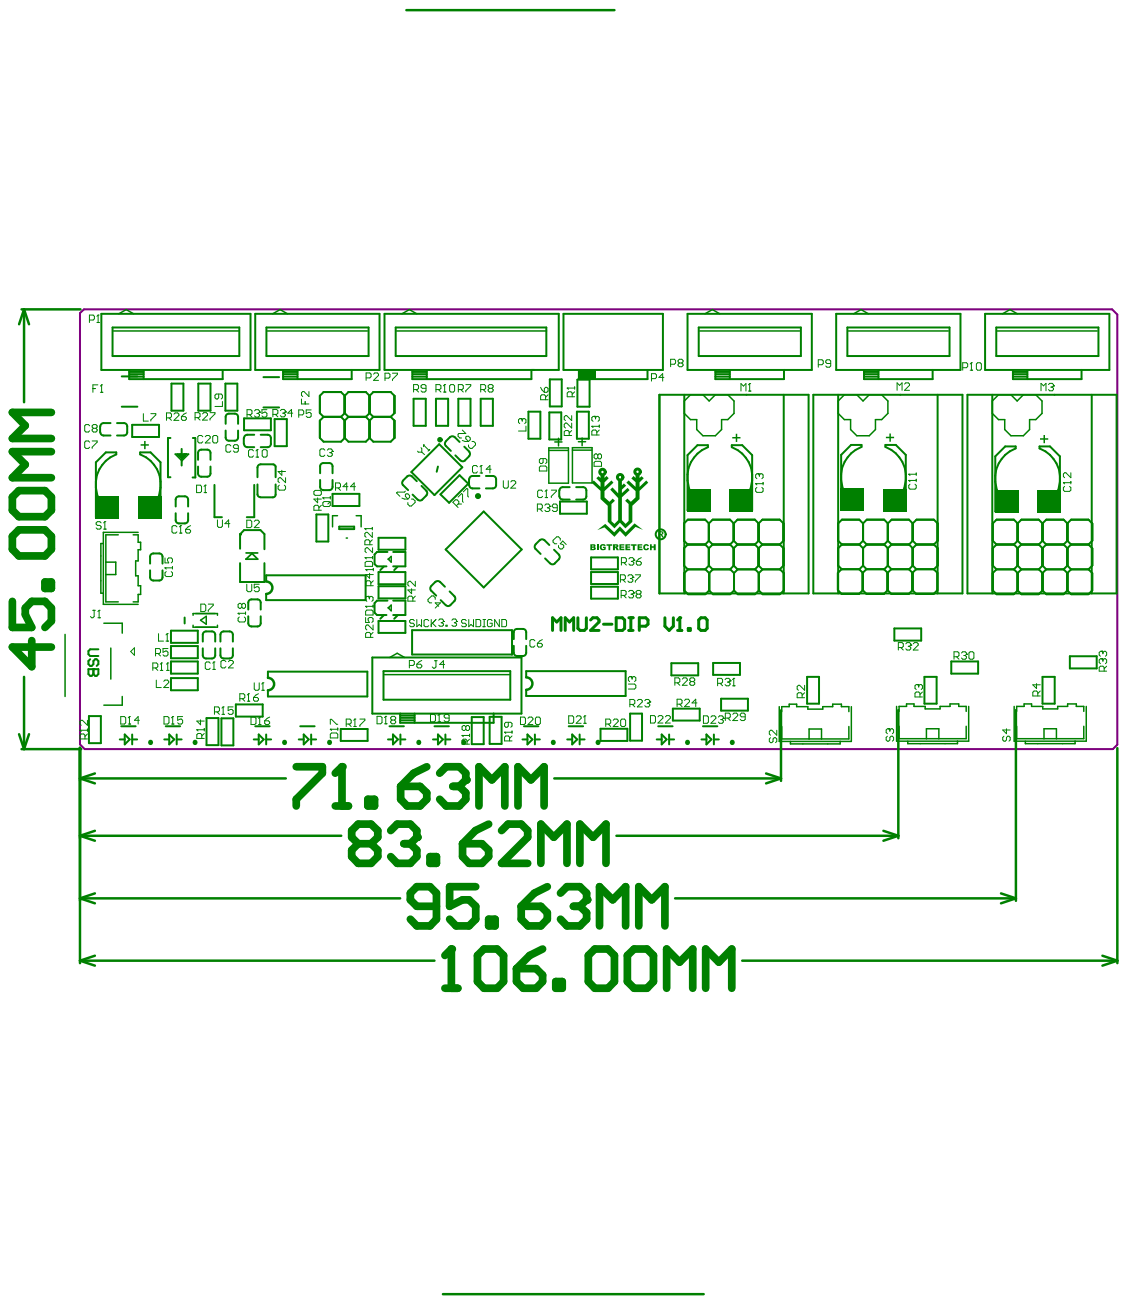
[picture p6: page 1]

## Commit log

2021-04-15 Update pin diagram
2022-03-31 upload schematic
2022-07-04 add 3D model source file
    [Electronics cover MMU2.STEP, Electronics cover MMU2.x_t]
2022-07-04 remove x_t
    [Electronics cover MMU2.x_t]
2022-07-12 Update MMU2-DIP Electronics Cover (#19)
    [Electronics cover MMU2.STEP, Electronics cover MMU2.STL, mmu2-dip-ele-cover-v2.step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]
